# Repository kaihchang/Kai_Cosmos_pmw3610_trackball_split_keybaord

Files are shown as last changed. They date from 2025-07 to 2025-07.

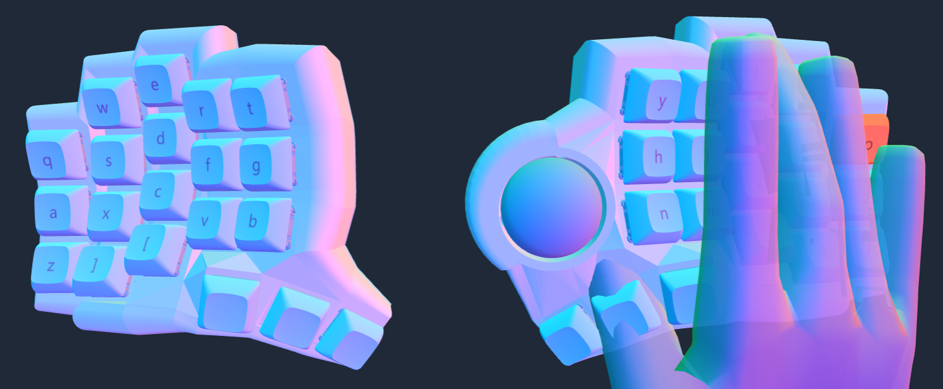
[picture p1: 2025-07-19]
case_print_file/cosmos_configurator.png

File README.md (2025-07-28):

# Kai Cosmos 40, a ZMK split keyboard with pmw3610 trackball

👉 ZMK firmware |
[Dongle-less](https://github.com/kaihchang/zmk-config-kai-cosmos) |
[With Dongle](https://github.com/kaihchang/zmk-config-kai-cosmos-dongle)

PXL_20250728_055040921~2





Design is mostly created using [rianadon's Cosmos Keyboard Configurator](https://github.com/rianadon/Cosmos-Keyboards). Highly recommend! It's a godsend.

What I did:
1. Scan my own hands with the tools Cosmos Keyboard Configurator provided and my phone's camera.
2. Add a 34mm trackball with [Skree ZMK pmw3610 board](https://github.com/siderakb/pmw3610-pcb) to the right side, which will also be ZMK's main side.
3. Download the models and edit in Blender and Fusion to smooth out the corners.
4. Using the microcontroller template from Cosmos Keyboard Configurator to draw out PCB in Kicad.
5. Implement [badjeff's zmk-pmw3610-driver](https://github.com/badjeff/zmk-pmw3610-driver/tree/main) with some official ZMK settings. Documentations aren't really clear, I recommend searching certain attributes and copying from public repos on Github.
6. Solder, test, change keymap, rinse and repeat.
cosmos_configurator
mcu_holder

Things for further improvements:
1. Reset button should be set under MCU holder PCB for easier access.
2. Should have cutouts under MCUs to make built-in LEDs more visible.
3. Should have copper keep out zones beneath MCU's antennae for better Bluetooth signal.
4. Not crucial but important, pmw3610 orientation does matter, since with official settings you can only rotate it in 90-degree increments. Fortunately worked out for me, but I didn't know this beforehand.

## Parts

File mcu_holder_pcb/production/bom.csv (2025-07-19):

Designator | Footprint | Quantity | Value | LCSC Part #
H1, H2, H3 | mouse-bite-2mm-slot | 3 | MountingHole_Pad
J1 | JST_XH_2.54mm_vertical | 1 | BAT_connector_left
J2 | JST_XH_2.54mm_vertical | 1 | BAT_connector_right
J3, J4 | PinHeader_1x04_P2.54mm_Vertical | 2 | Conn_01x04_Socket
J5, J6 | PinHeader_1x05_P2.54mm_Vertical | 2 | Ribbon
J7 | PinHeader_1x06_P2.54mm_Vertical | 1 | pmw3610_connector
RESET_2 | SW_SPST_CK_RS282G05A3 | 1 | switch_reset_left
RESET | SW_SPST_CK_RS282G05A3 | 1 | switch_reset_right
SW3, SW4 | 200AWMSP2T2A1M6RE | 2 | ~
U1 | Arduino_Pro_Micro_Flipped | 1 | nice!nano_flipped_left
U2 | Arduino_Pro_Micro_Flipped | 1 | nice!nano_flipped_right

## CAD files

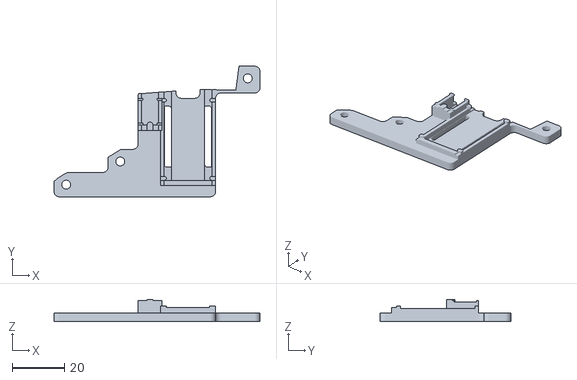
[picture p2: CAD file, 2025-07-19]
case_print_file/kai_cosmos-holderright.stl
78.6 x 49.8 x 8.50

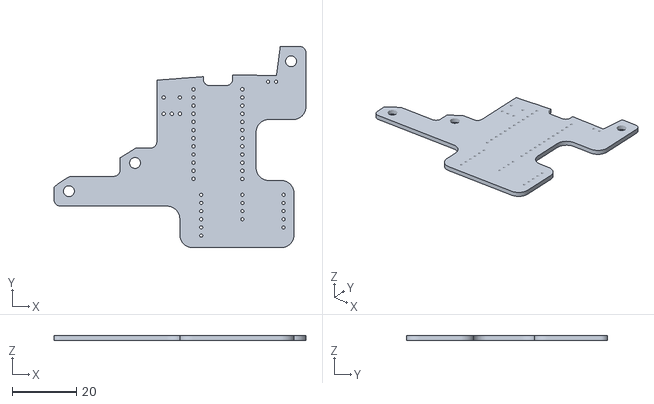
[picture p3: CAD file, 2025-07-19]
mcu_holder_pcb/cosmos40_mcu_holder_PCB_right.stl
78.6 x 62.7 x 1.60

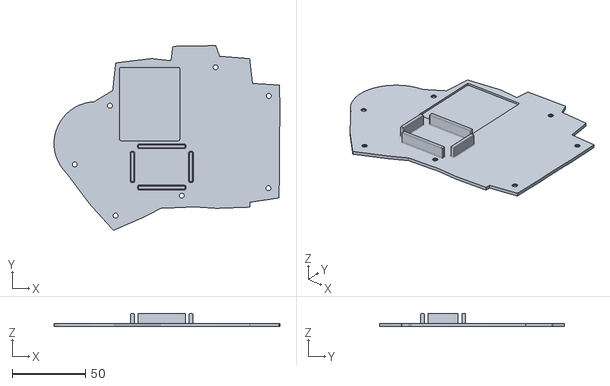
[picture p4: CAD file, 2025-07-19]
case_print_file/kai_cosmos-plateright.stl
154.0 x 125.9 x 9.00

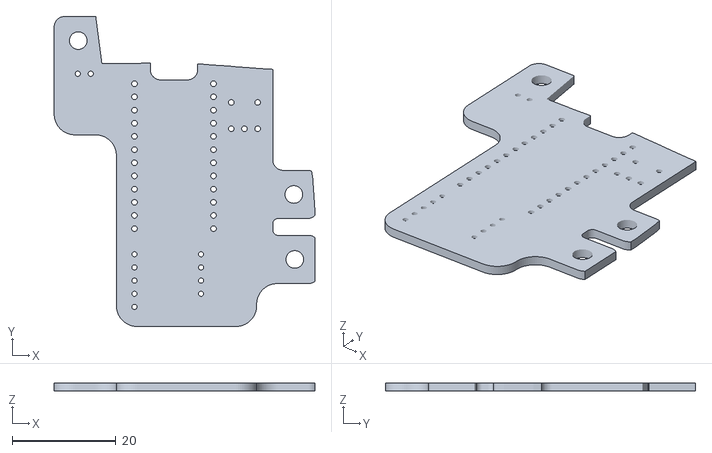
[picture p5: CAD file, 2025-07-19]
mcu_holder_pcb/cosmos40_mcu_holder_PCB_left.stl
50.3 x 59.8 x 1.60

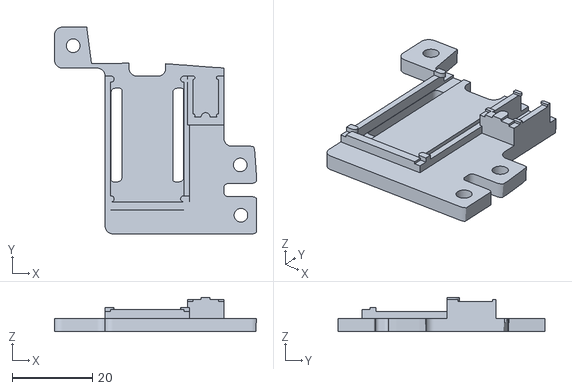
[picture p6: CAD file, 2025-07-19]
case_print_file/kai_cosmos-holderleft.stl
50.3 x 51.5 x 8.50

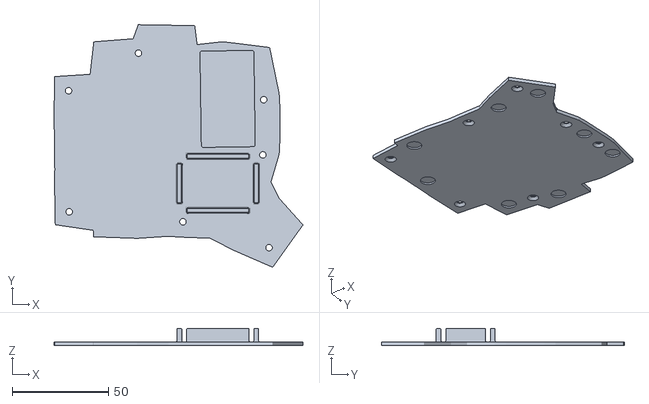
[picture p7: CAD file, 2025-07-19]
case_print_file/kai_cosmos-plateleft.stl
129.2 x 125.9 x 9.00

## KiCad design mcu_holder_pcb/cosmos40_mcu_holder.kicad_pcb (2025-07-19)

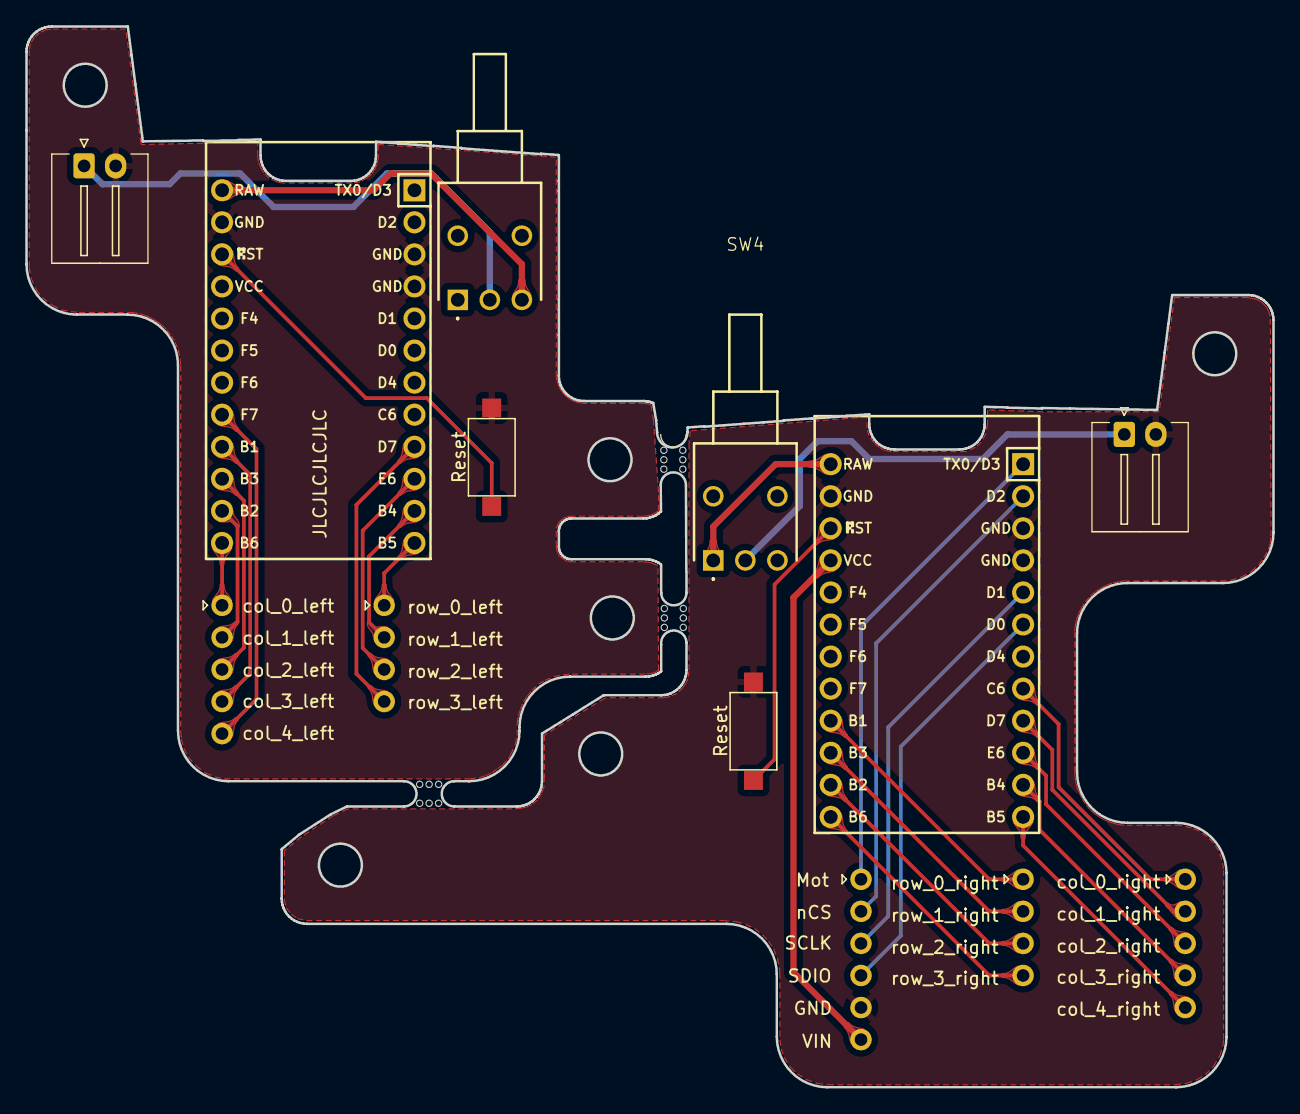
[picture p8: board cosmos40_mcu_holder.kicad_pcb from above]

Board: 2 copper layers, 98.8 x 84.0 mm, 16 parts (0 on the bottom side), 31 nets.

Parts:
H1, H2, H3: MountingHole_Pad; mouse-bite-2mm-slot
J1: BAT_connector_left; JST_XH_2.54mm_vertical
J2: BAT_connector_right; JST_XH_2.54mm_vertical
J3, J4: Conn_01x04_Socket; PinHeader_1x04_P2.54mm_Vertical
J5, J6: Ribbon; PinHeader_1x05_P2.54mm_Vertical
J7: pmw3610_connector; PinHeader_1x06_P2.54mm_Vertical
Reset: switch_reset_left; SW_SPST_CK_RS282G05A3
Reset#2: switch_reset_right; SW_SPST_CK_RS282G05A3
SW3, SW4: 200AWMSP2T2A1M6RE
U1: nice!nano_flipped_left; Arduino_Pro_Micro_Flipped
U2: nice!nano_flipped_right; Arduino_Pro_Micro_Flipped

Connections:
BAT_left: J1.1, SW3.2 (COM)
BAT_right: J2.1, SW4.2 (COM)
GND_left: J1.2, Reset.2 (B), U1.3 (GND), U1.4 (GND), U1.23 (GND)
GND_right: J2.2, J7.5, Reset#2.2 (B), U2.3 (GND), U2.4 (GND), U2.23 (GND)
Mot: J7.1, U2.1 (TX0/P0.06)
RST_left: Reset.1 (A), U1.22 (RST)
RST_right: Reset#2.1 (A), U2.22 (RST)
SCLK: J7.3, U2.5 (P0.17)
SDIO: J7.4, U2.6 (P0.20)
VIN: J7.6, U2.21 (VCC)
col_0_left: J5.1, U1.13 (NFC1/P0.09)
col_0_right: J6.1, U2.8 (P0.24)
col_1_left: J5.2, U1.14 (NFC2/P0.10)
col_1_right: J6.2, U2.9 (P1.00)
col_2_left: J5.3, U1.15 (P1.11)
col_2_right: J6.3, U2.10 (P0.11)
col_3_left: J5.4, U1.16 (P1.13)
col_3_right: J6.4, U2.11 (P1.04)
col_4_left: J5.5, U1.17 (P1.15)
col_4_right: J6.5, U2.12 (P1.06)
nCS: J7.2, U2.2 (RX1/P0.08)
power_sw_left: SW3.3 (NO), U1.24 (BATIN/P0.04)
power_sw_right: SW4.1 (NC), U2.24 (BATIN/P0.04)
row_0_left: J3.1, U1.12 (P1.06)
row_0_right: J4.1, U2.16 (P1.13)
row_1_left: J3.2, U1.11 (P1.04)
row_1_right: J4.2, U2.15 (P1.11)
row_2_left: J3.3, U1.10 (P0.11)
row_2_right: J4.3, U2.14 (NFC2/P0.10)
row_3_left: J3.4, U1.9 (P1.00)
row_3_right: J4.4, U2.13 (NFC1/P0.09)

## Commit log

2025-07-19 full file innitial commit
    [kai_cosmos-holderleft.stl, kai_cosmos-holderright.stl, kai_cosmos-plateleft.stl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]
2025-07-19 change files
    [bom.csv, cosmos40_mcu_holder.kicad_pcb, cosmos40_mcu_holder.kicad_sch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]
